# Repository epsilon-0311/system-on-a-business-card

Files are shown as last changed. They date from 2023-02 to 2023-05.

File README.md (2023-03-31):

# system-on-a-business-card (SoBC)

The System on a Business Card is a miniature system in the size of a business card.
It is controlled by a ESP32-C3 microncontroller which shall run Zephyr RTOS in the future.
Since this goal is to also use the PCB is a business card, the predominant factor is the size which is 55x85 mm which seems to be the standard, at least for Europe.

A interactive Bill of Materials for the latest released board revision can be found [here](KiCAD/system-on-a-business-card/bom/ibom.html).
Alternatively, if you have the repositoy open on Github, please use this [link](https://htmlpreview.github.io/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). 

For further details on how to customize the desing to add your contact details please have a look at [Customization of the PCB](KiCAD/doc/README.md#Customization-of-the-PCB).

## Hardware Design

The system uses the on-board USB Type C recepticle for power delivery and a ESP32-C3 as its host.
As the microcontroller also supports Bluetooth and Wifi the design includes a PCB antenna as well.
One of the most prominent elements of the board is 0.77 inch OLED screen which is used to display various graphics.
Instead of using typical low profile buttons the board has resistive touch pads for the main controls.
More details on the harware design can be found [here](KiCAD/doc/README.md).

Design renderings of a revision 1.A PCB:
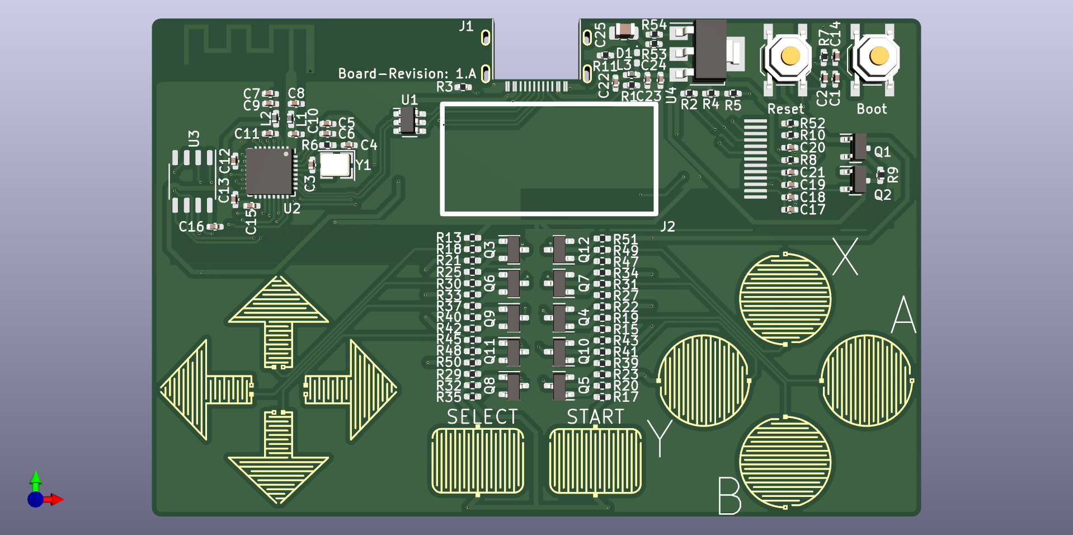
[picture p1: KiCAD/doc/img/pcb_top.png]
PCB_Top

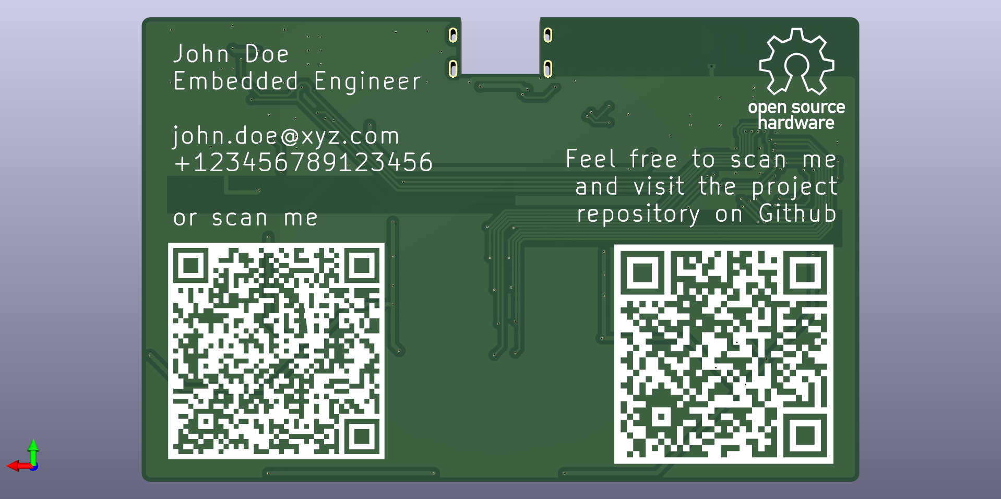
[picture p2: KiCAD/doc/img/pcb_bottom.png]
PCB_Bottom

Finished board revision 1.A PCB:
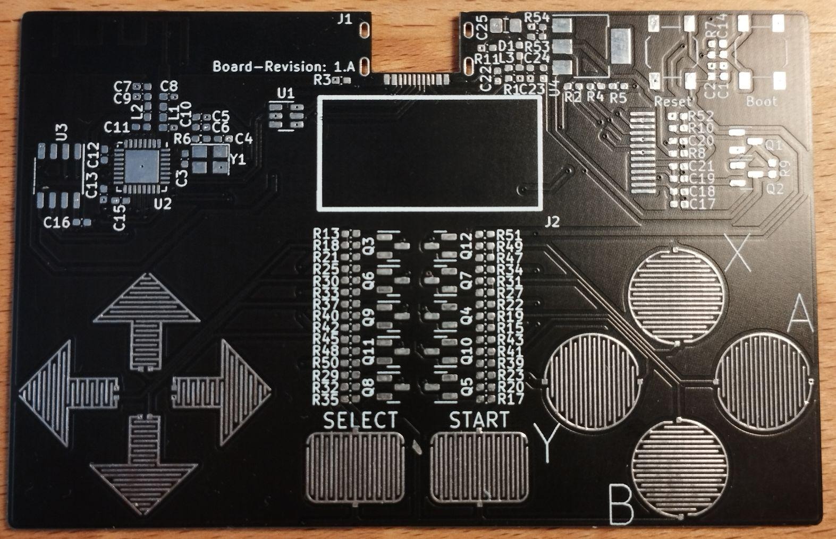
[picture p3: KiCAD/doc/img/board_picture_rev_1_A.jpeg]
board_picture_rev_1_A


Fully assembled revision 1.A PCB:
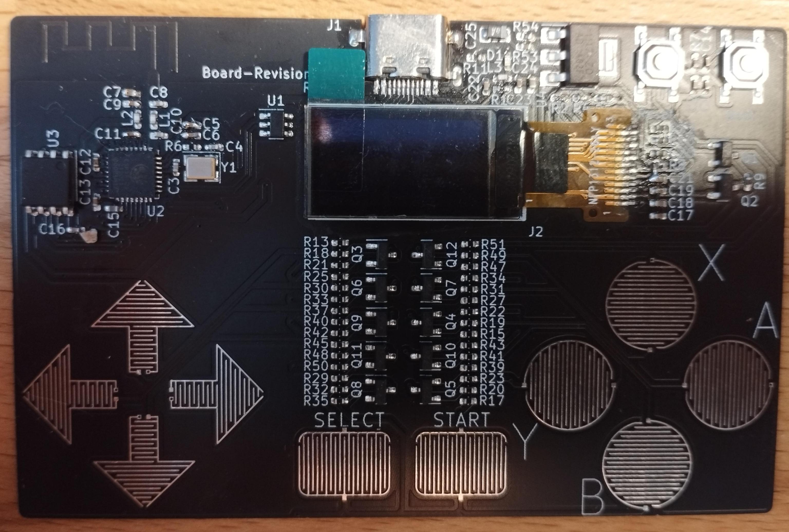
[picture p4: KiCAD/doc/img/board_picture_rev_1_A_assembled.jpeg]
assembled_board_picture_rev_1_A


## Zephyr
At the moment I'm working on getting Zephyr running.
A basic hardware configuration for the board is already available inside the Zephyr directory.
It builds and a minimal example is also available.
Unfortunately, I'm still waiting on my parts to finish the boards of my first batch.

As soon as I have a functioning board configuration, the goal is to submit the board to Zephry such that is officially supported.
Further, Zephyr currently does not support the used OLED dispaly controller (SSD1312).
Therefore, an additional goal is to submit a driver to the Zephyr project.

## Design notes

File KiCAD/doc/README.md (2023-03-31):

# Hardware Design

The system uses the on-board USB Type C recepticle for power delivery and converts the 5V to 3.3V using an LDO.
Since the ESP32-C3 has a USB interface and provides a serial interface as well as a JTAG no additional UART connector is on the board.
As the microcontroller also supports the connection of an antenne, there is also a PCB inverted F antenna on the top left of the board.
One of the most prominent elements of the board is 0.77 inch OLED screen which is connected via I2C to the host and is powered via the USB's 5V.
Instead of using typical low profile buttons, like on the top for BOOT and RESET, the board has resistive touch pads. 
As a small added benefit this design decision also reduces costs.

Since this PCB was designed to be also used as a business card, we opted for a thickness of 0.8mm. 
Main reason for the selected thickness, is that JLCPCB does not charge extra for PCB's between 0.8 and 1.6 mm.
This has to be taken with a grain of salt, other may charge extra for this.
The design for the antenna would be simpler to match the impedance, if a 4-Layer would be used. 
Unfortunately, with the thinner PCB significant extra costs would be added when using more layers.

## Board Revision History

A board revisions looks as follows ``MAJOR.MINOR.PATCH``.
``MAJOR`` revisions indicate some fundamental changes in the design, e.g, a new host. 
``MINOR`` revisions indicate changes in the hardware design, which requires a change in e.g. the Zephyr device tree.
Different ``PATCH`` versions indicate some minor changes in the design, which does not affect the software side.

| Revision | Local Link | Github Link | Release Package | Comments |
|---|---|---|---|---|
| 1.0.0/1.A  | [BOM](../system-on-a-business-card/bom/ibom_rev_1_0_0.html) | [BOM](https://htmlpreview.github.io/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)| [Package](https://github.com/epsilon-0311/system-on-a-business-card/releases/tag/board_rev_1_0_0) | Initial Version |
| 1.0.1 | [BOM](../system-on-a-business-card/bom/ibom_rev_1_0_1.html) | [BOM](https://htmlpreview.github.io/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)| [Package](https://github.com/epsilon-0311/system-on-a-business-card/releases/tag/board_rev_1_0_1) | <ul><li>Fixed unconnected OLED Logic Supply Voltage</li><li>Updated Resistor to dimm LED D1</li><li>Fixed Flash  IC Footprint</li></ul> |

The first batch was produced using the revision 1.A.
In order to provide a revision compatible with Zephyr, it was changed to ``1.0.0``.

## Antenna Impedance Trace Width Matching

As this design utilises a PCB Antenna, impedance matched traces are required.
The calculations assummed a surface micrstrip design.
From the manufacturer JLCPCB we know a copper thickness of 1 oz/35µm(see [Finished Outer Layer Copper](https://jlcpcb.com/capabilities/pcb-capabilities)) and a dilectric contant of 4.5 (see [Dielectric constant](https://jlcpcb.com/capabilities/pcb-capabilities)).
Using this [calculator](https://www.pcbway.com/pcb_prototype/impedance_calculator.html) we calculated a required track width of 1.45 mm to achieve a impedance of 50 Ohm.
Due to space limiations we opted for a trace width of 1.2 mm.

# Customization of the PCB
As this is a business card, it shall display your contact information.
Therefore, the bottom silkscreen layer provides a text field for this.
In addition, below the text field I added a QR-Code which was generated using [this online generator](https://goqr.me/#t=vcard). 

To modify this open the PCB design view of KiCAD and best hide all layers except Edge.Cuts and B.Silkscreen.
On the right side you find the text box for your contact information and below there is some space to place the QR-Code.
The QR-Code needs to be available as svg graphic and can be imported via File->Import->Graphics.
If you use the same generator, you can import the svg with a scaling factor of 0.375.

# Sourcing Guide 

You can find a sourcing guide using [JLCPCB](https://jlcpcb.com/) and [LCSC](https://www.lcsc.com/) as PCB manufacturer and parts suppliere here: [Link](https://docs.google.com/spreadsheets/d/16gFrFvvIfR94LbLsq9TxAxXNphaDNR22jH06x7NUitE/edit?usp=sharing). 
With the components selected in this Google Spreads, a single PCB with parts will cost around 4€, if at least 10 are manufactured.
Due to varying costs on the shipment destination, shipment costs were not included in the calculation.

The original goal was to be at around 3€ per board.
The main cost factors are the used microcontroller (ESP32-C3) and the 0.77 inch OLED display.
If you are aware of components that can reduce the price, feel free to discuss it in the discussion section on GitHub. 

# Possible Future updates to the Design

## ESP32-C6
Esprressif has announced the ESP32-C6 with a high and a lowe power core and more wireless connectivity standards.
At the moment the chip is not available on my default parts provider (LCSC), but it would be nice to check it out due to its more powerfull CPU.
Further investigation is strongly dependent on the price.

## USB Ciruitry
Currently the design simply pulls power through the USB plug, but this violates the USB specification. 
For future revisions it would be awesome to add a USB power negotion circuit to board to add comformoty. 
If you're familiar with the design of such circuits feel free to add some comments.

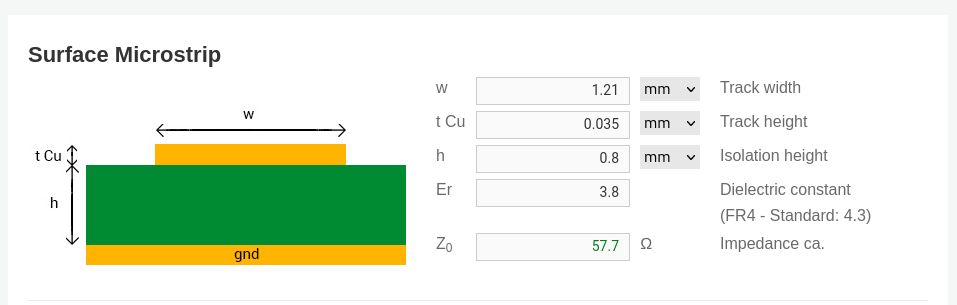
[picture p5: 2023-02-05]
KiCAD/doc/img/impedance_calculation.png

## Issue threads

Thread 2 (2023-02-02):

Zephyr Bring-Up

epsilon-0311, 2023-02-02:
To get Zephyr running on a new board the following steps need to be performed.

- [x] devicetree file : Hardware definition file
- [x] KConfig files : Softare configuration files
- - [x] Kconfig.board
- - [x] Kconfig.defconfig
- - [x]  sobc_defconfig

Optional Files

- [x] board.cmake : Build and flash configuration
- [ ] ~~ doc/index.rst and doc/sobc.png : Documentation for submission to Zephyr ~~
- [ ] ~~ sobc.yaml: a YAML file with miscellaneous metadata used by the Test Runner (Twister) ~~

Steps:
- [x]  Get Zephyr Running
- [ ]  ~~ Add Documentation ~~
- [ ]  ~~  Contibute to [Zephyr](https://docs.zephyrproject.org/latest/hardware/porting/board_porting.html#contributing-your-board)~~

epsilon-0311, 2023-02-03:
Hardware and Software configuration files added and compile. Final testing requires hardware which is still in transit

epsilon-0311, 2023-03-25:
The board does not use a dedicated UART interface. Instead, it uses USB-CDC, which needs to be configured for Zephyr

epsilon-0311, 2023-09-02:
Zephyr now works, closing issue

Closed 2023-09-02.

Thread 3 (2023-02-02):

USB Power Delivery

epsilon-0311, 2023-02-02:
Currently, the board simply takes power from the USB-Receptacle violating the Specification.
In the future the board shall use circuitry such this is compliant.

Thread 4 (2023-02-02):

OLED driver

epsilon-0311, 2023-02-02:
The used [OLED display](https://www.lcsc.com/product-detail/_Shenzhen-Allvision-Tech-_C5123562.html) uses the [SSD1312](https://www.buydisplay.com/download/ic/SSD1312_Datasheet.pdf).
This controller is not officially supported by Zephry.

- [x] Check SSD1306 [datasheet](https://cdn-shop.adafruit.com/datasheets/SSD1306.pdf)  and [driver](https://github.com/zephyrproject-rtos/zephyr/tree/main/boards/shields/ssd1306)
- [x] Create SSD1312 shield device tree overlay
- [x] Implement SSD1312 driver
- [x] Add SSD1312 to board device tree
- [ ] Contribute driver to Zephyr

epsilon-0311, 2023-04-08:
Checkout the files from SSD1306:

- [ssd1306_128x64.overlay](https://github.com/zephyrproject-rtos/zephyr/blob/main/boards/shields/ssd1306/ssd1306_128x64.overlay)
- [ssd1306.c](https://github.com/zephyrproject-rtos/zephyr/blob/main/drivers/display/ssd1306.c)
- [KConfig](https://github.com/zephyrproject-rtos/zephyr/blob/main/drivers/display/Kconfig.ssd1306)

epsilon-0311, 2023-04-08:
Checkout the files from SSD1306:

- [ssd1306_128x64.overlay](https://github.com/zephyrproject-rtos/zephyr/blob/main/boards/shields/ssd1306/ssd1306_128x64.overlay)
- [ssd1306.c](https://github.com/zephyrproject-rtos/zephyr/blob/main/drivers/display/ssd1306.c)
- [KConfig](https://github.com/zephyrproject-rtos/zephyr/blob/main/drivers/display/Kconfig.ssd1306)

epsilon-0311, 2023-06-11:
Contribution to Zephyr is skipped for now.

Closed 2023-06-11.

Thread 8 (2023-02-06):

SMT Stencil Mount

epsilon-0311, 2023-02-06:
Would be nice to design a SMT stencil holder for easy application of the solder paste. It should be 3D-printable.

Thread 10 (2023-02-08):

Board Revision 1.0.1

epsilon-0311, 2023-02-08:
In this issue planned improvements for the board revision 1.0.1 are stored:

- [ ]  add rounded corners to the USB Plug cut out

epsilon-0311, 2023-03-10:
the voltage divider should work without the transistor switching the MCU, check if this is possible  as it would significantly reduce the component count

epsilon-0311, 2023-04-06:
Test using the voltage divider without the transistor, still works. This should be implemented to reduce component count.

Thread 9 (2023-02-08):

Scripting Support

epsilon-0311, 2023-02-08:
KiCAD has a python API which allows scripting amongst other things an automated export of gerber files.
It would be nice to provide some tooling which eases swapping QR-codes and contact details

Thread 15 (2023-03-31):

Connection to LED inside PI Filter

epsilon-0311, 2023-03-31:
The connection to the LED D1 is inside the PI filter.  The wire should be moved after the filter.

Closed 2023-03-31.

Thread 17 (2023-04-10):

ZD1117ILTRAD resistor values

epsilon-0311, 2023-04-10:
I rechecked the design guidelines for the ZD1117ILTRAD, the current design works but the resistors should be adapted to meet the guidelines

epsilon-0311, 2023-04-10:
Replace R53 with a 121 Ohm and R54 with 75 Ohm Resistor

Closed 2023-04-10.

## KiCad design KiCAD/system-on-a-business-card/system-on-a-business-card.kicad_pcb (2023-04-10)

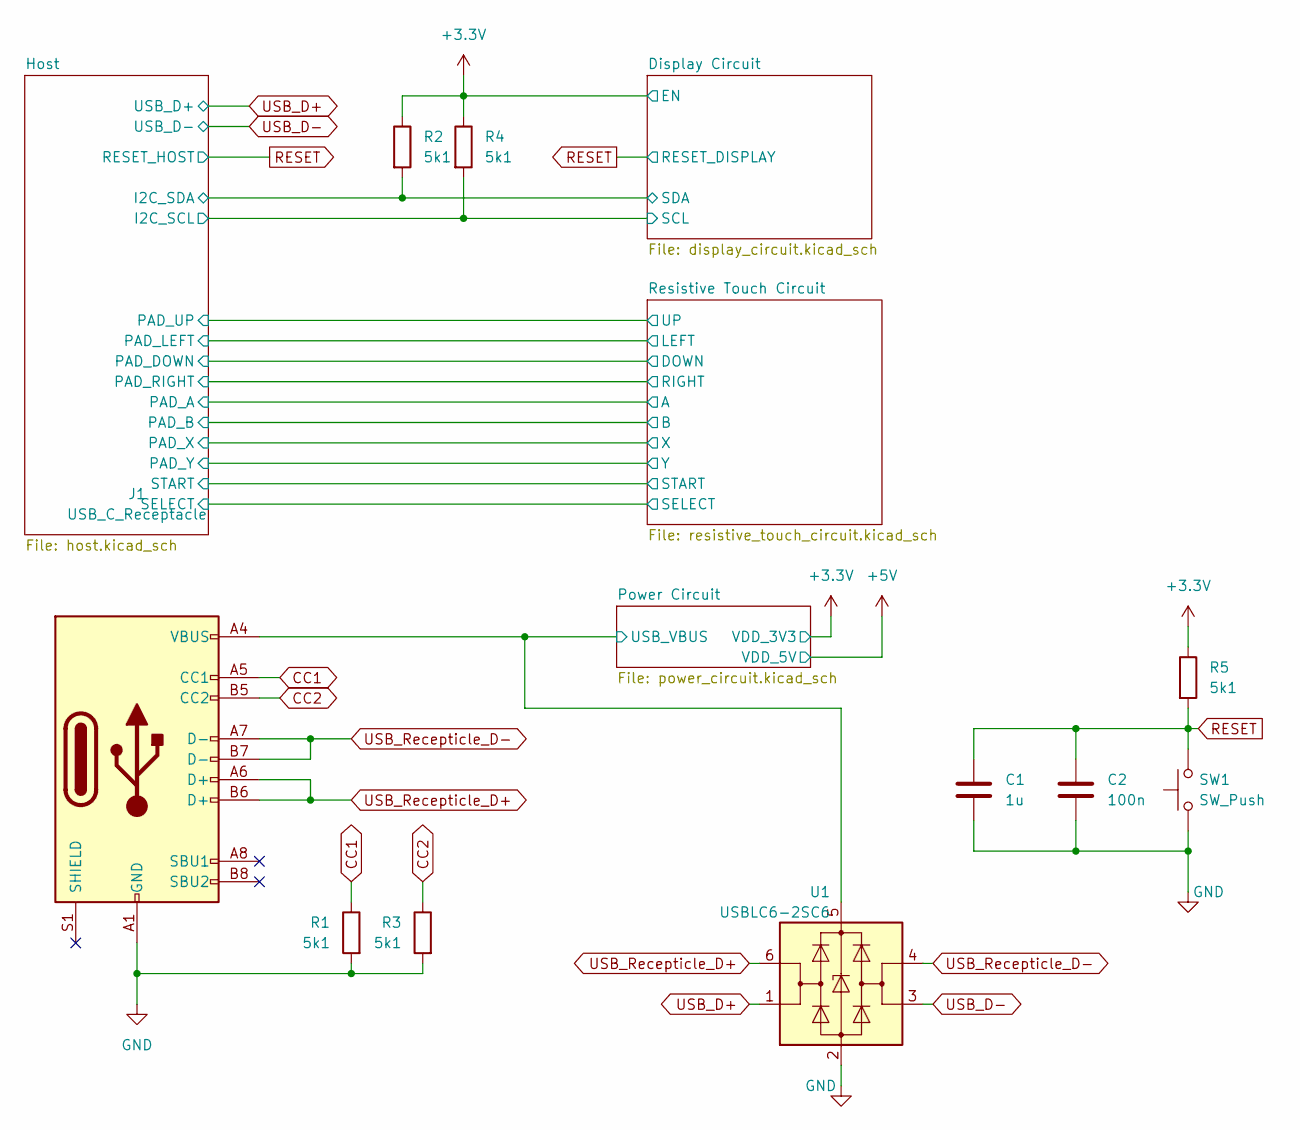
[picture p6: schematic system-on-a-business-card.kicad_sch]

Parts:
C1: 1u; C_0402_1005Metric_Pad0.74x0.62mm_HandSolder
C2: 100n; C_0402_1005Metric_Pad0.74x0.62mm_HandSolder
J1: USB_C_Receptacle; USB_C_Receptacle_SHOU_HAN_TYPE_C_16P_CB1.6_073
R1, R2, R3, R4, R5: 5k1; R_0402_1005Metric_Pad0.72x0.64mm_HandSolder
SW1: SW_Push; SW_SPST_TL3342
U1: USBLC6-2SC6; SOT-23-6

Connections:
+3.3V: R2.1, R4.1, R5.1; also elsewhere on the board
/Display Circuit/SCL: R4.2; also elsewhere on the board
/Display Circuit/SDA: R2.2; also elsewhere on the board
/Power Circuit/USB_VBUS: J1.A4 (VBUS), J1.A9 (VBUS), J1.B4 (VBUS), J1.B9 (VBUS), U1.5 (VBUS); also elsewhere on the board
CC1: J1.A5 (CC1), R1.1
CC2: J1.B5 (CC2), R3.1
GND: C1.2, C2.2, J1.A1 (GND), J1.A12 (GND), J1.B1 (GND), J1.B12 (GND), R1.2, R3.2, SW1.1, U1.2 (GND); also elsewhere on the board
RESET: C1.1, C2.1, R5.2, SW1.2; also elsewhere on the board
USB_D+: U1.1 (I/O1); also elsewhere on the board
USB_D-: U1.3 (I/O2); also elsewhere on the board
USB_Recepticle_D+: J1.A6 (D+), J1.B6 (D+), U1.6 (I/O1)
USB_Recepticle_D-: J1.A7 (D-), J1.B7 (D-), U1.4 (I/O2)

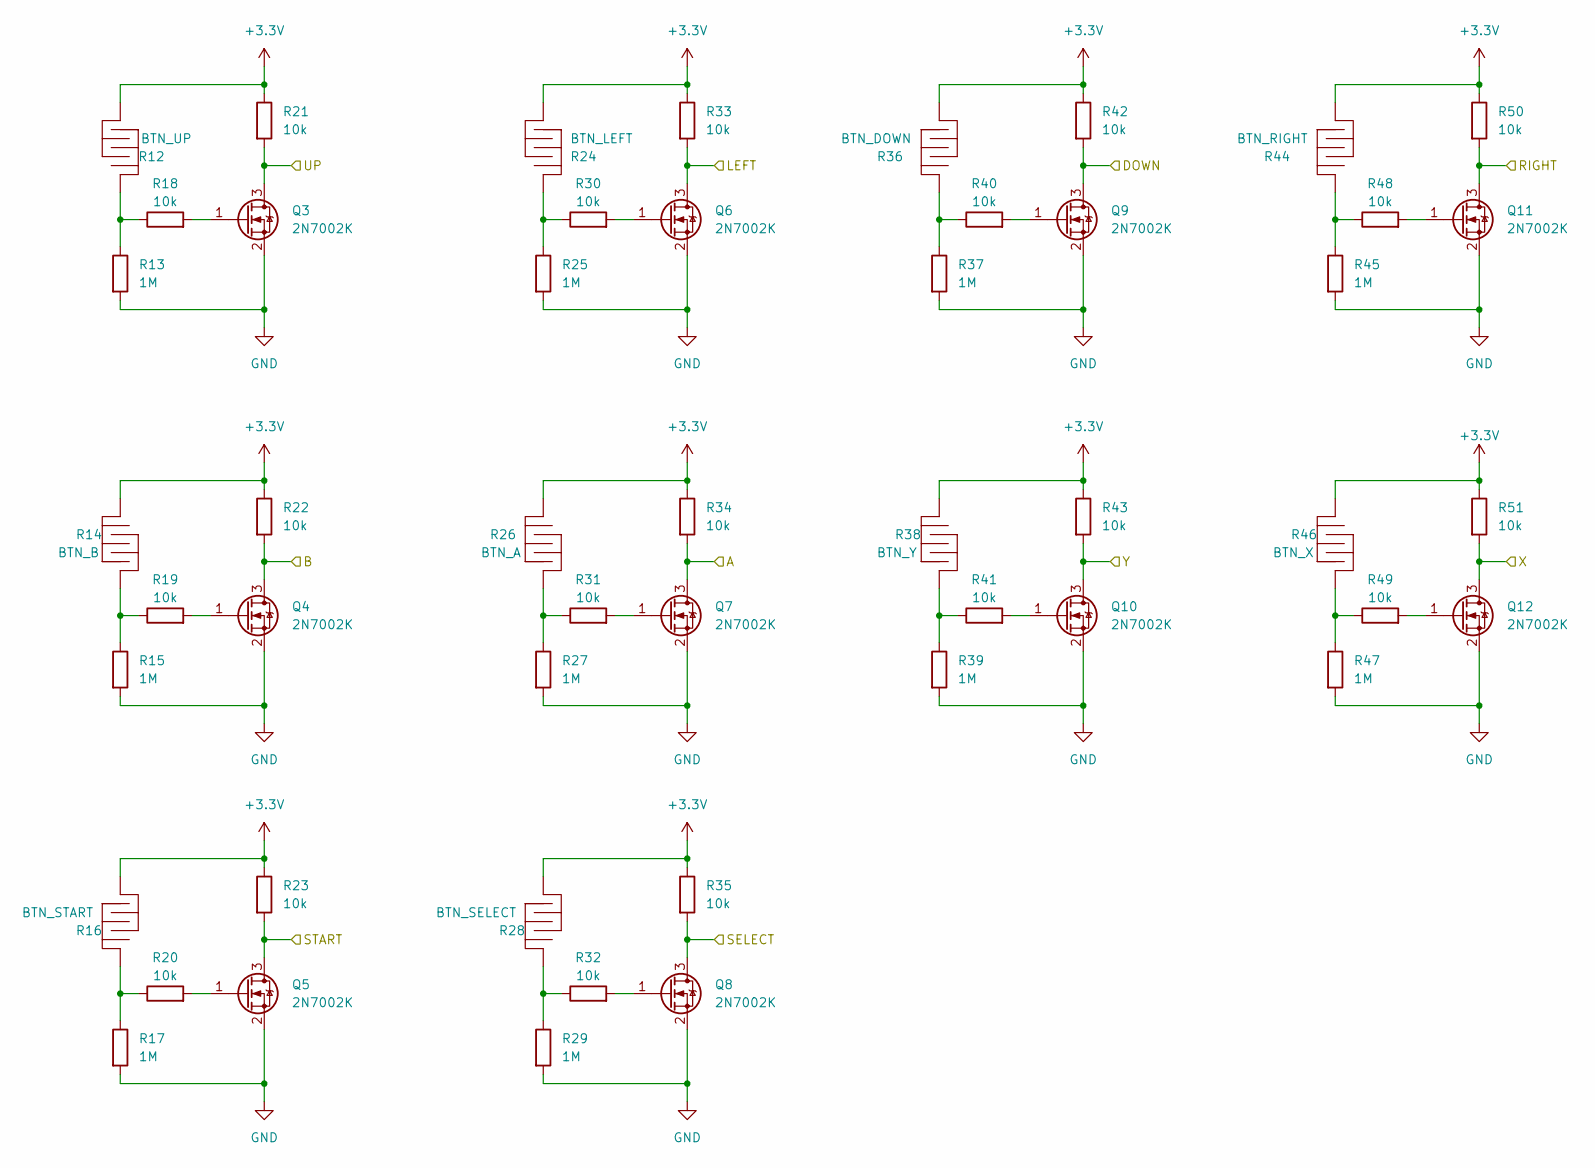
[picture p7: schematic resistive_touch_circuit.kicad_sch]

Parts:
Q3, Q4, Q5, Q6, Q7, Q8, Q9, Q10, Q11, Q12: 2N7002K; SOT-23
R12: BTN_UP; Resistive_Pad_Arrow_10mm
R13, R15, R17, R25, R27, R29, R37, R39, R45, R47: 1M; R_0402_1005Metric_Pad0.72x0.64mm_HandSolder
R14: BTN_B; Resistive_Pad_round_10_mm
R16: BTN_START; Resistive_Pad_rectangular_rounded_7x10mm
R18, R19, R20, R21, R22, R23, R30, R31, R32, R33, R34, R35, R40, R41, R42, R43, R48, R49, R50, R51: 10k; R_0402_1005Metric_Pad0.72x0.64mm_HandSolder
R24: BTN_LEFT; Resistive_Pad_Arrow_10mm
R26: BTN_A; Resistive_Pad_round_10_mm
R28: BTN_SELECT; Resistive_Pad_rectangular_rounded_7x10mm
R36: BTN_DOWN; Resistive_Pad_Arrow_10mm
R38: BTN_Y; Resistive_Pad_round_10_mm
R44: BTN_RIGHT; Resistive_Pad_Arrow_10mm
R46: BTN_X; Resistive_Pad_round_10_mm

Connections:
+3.3V: R12.2, R14.1, R16.2, R21.1, R22.1, R23.1, R24.2, R26.1, R28.2, R33.1, R34.1, R35.1, R36.2, R38.1, R42.1, R43.1, R44.2, R46.1, R50.1, R51.1; also elsewhere on the board
/Host/PAD_A: Q7.3 (D), R34.2; also elsewhere on the board
/Host/PAD_B: Q4.3 (D), R22.2; also elsewhere on the board
/Host/PAD_DOWN: Q9.3 (D), R42.2; also elsewhere on the board
/Host/PAD_LEFT: Q6.3 (D), R33.2; also elsewhere on the board
/Host/PAD_RIGHT: Q11.3 (D), R50.2; also elsewhere on the board
/Host/PAD_UP: Q3.3 (D), R21.2; also elsewhere on the board
/Host/PAD_X: Q12.3 (D), R51.2; also elsewhere on the board
/Host/PAD_Y: Q10.3 (D), R43.2; also elsewhere on the board
/Host/SELECT: Q8.3 (D), R35.2; also elsewhere on the board
/Host/START: Q5.3 (D), R23.2; also elsewhere on the board
GND: Q3.2 (S), Q4.2 (S), Q5.2 (S), Q6.2 (S), Q7.2 (S), Q8.2 (S), Q9.2 (S), Q10.2 (S), Q11.2 (S), Q12.2 (S), R13.2, R15.2, R17.2, R25.2, R27.2, R29.2, R37.2, R39.2, R45.2, R47.2; also elsewhere on the board
unnamed: Q3.1 (G), R18.2
unnamed: Q4.1 (G), R19.2
unnamed: Q5.1 (G), R20.2
unnamed: Q6.1 (G), R30.2
unnamed: Q7.1 (G), R31.2
unnamed: Q8.1 (G), R32.2
unnamed: Q9.1 (G), R40.2
unnamed: Q10.1 (G), R41.2
unnamed: Q11.1 (G), R48.2
unnamed: Q12.1 (G), R49.2
unnamed: R12.1, R13.1, R18.1
unnamed: R14.2, R15.1, R19.1
unnamed: R16.1, R17.1, R20.1
unnamed: R24.1, R25.1, R30.1
unnamed: R26.2, R27.1, R31.1
unnamed: R28.1, R29.1, R32.1
unnamed: R36.1, R37.1, R40.1
unnamed: R38.2, R39.1, R41.1
unnamed: R44.1, R45.1, R48.1
unnamed: R46.2, R47.1, R49.1

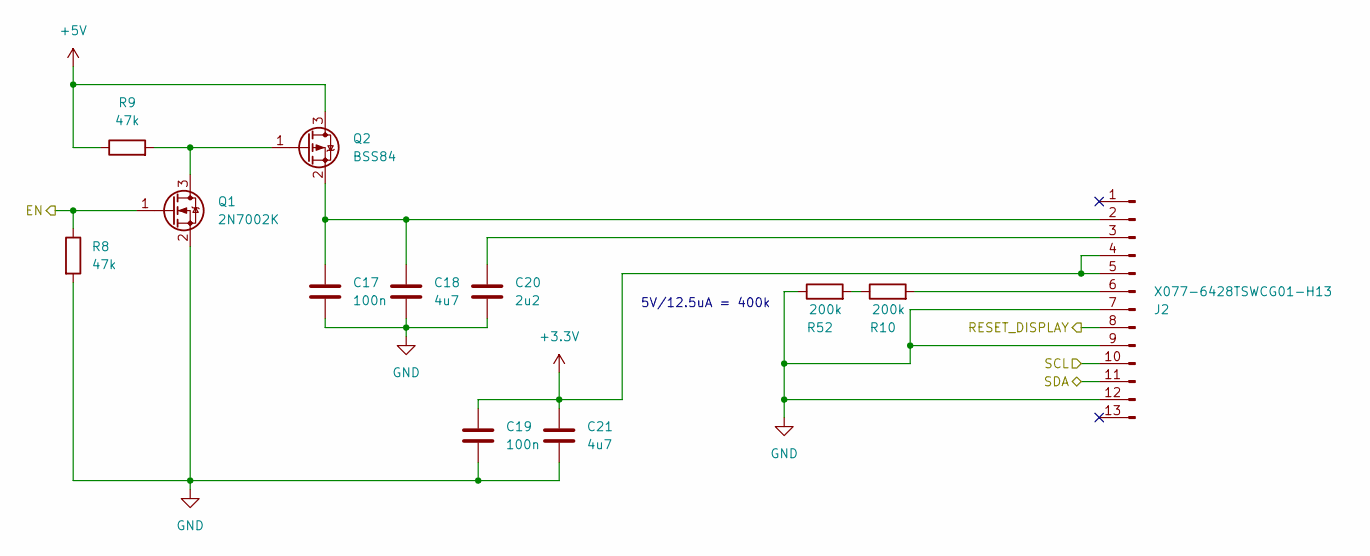
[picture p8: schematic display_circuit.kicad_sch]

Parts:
C17, C19: 100n; C_0402_1005Metric_Pad0.74x0.62mm_HandSolder
C18, C21: 4u7; C_0402_1005Metric_Pad0.74x0.62mm_HandSolder
C20: 2u2; C_0402_1005Metric_Pad0.74x0.62mm_HandSolder
J2: X077-6428TSWCG01-H13
Q1: 2N7002K; SOT-23
Q2: BSS84; SOT-23
R8, R9: 47k; R_0402_1005Metric_Pad0.72x0.64mm_HandSolder
R10, R52: 200k; R_0402_1005Metric_Pad0.72x0.64mm_HandSolder

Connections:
+3.3V: C19.1, C21.1, J2.4, J2.5, Q1.1 (G), R8.1; also elsewhere on the board
+5V: Q2.3 (D), R9.1; also elsewhere on the board
/Display Circuit/SCL: J2.10; also elsewhere on the board
/Display Circuit/SDA: J2.11; also elsewhere on the board
GND: C17.2, C18.2, C19.2, C20.2, C21.2, J2.7, J2.9, J2.12, Q1.2 (S), R8.2, R52.1; also elsewhere on the board
unnamed: C17.1, C18.1, J2.2, Q2.2 (S)
unnamed: C20.1, J2.3
unnamed: J2.6, R10.2
unnamed: Q1.3 (D), Q2.1 (G), R9.2
unnamed: R10.1, R52.2
RESET: J2.8; also elsewhere on the board

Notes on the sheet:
5V/12.5uA = 400k

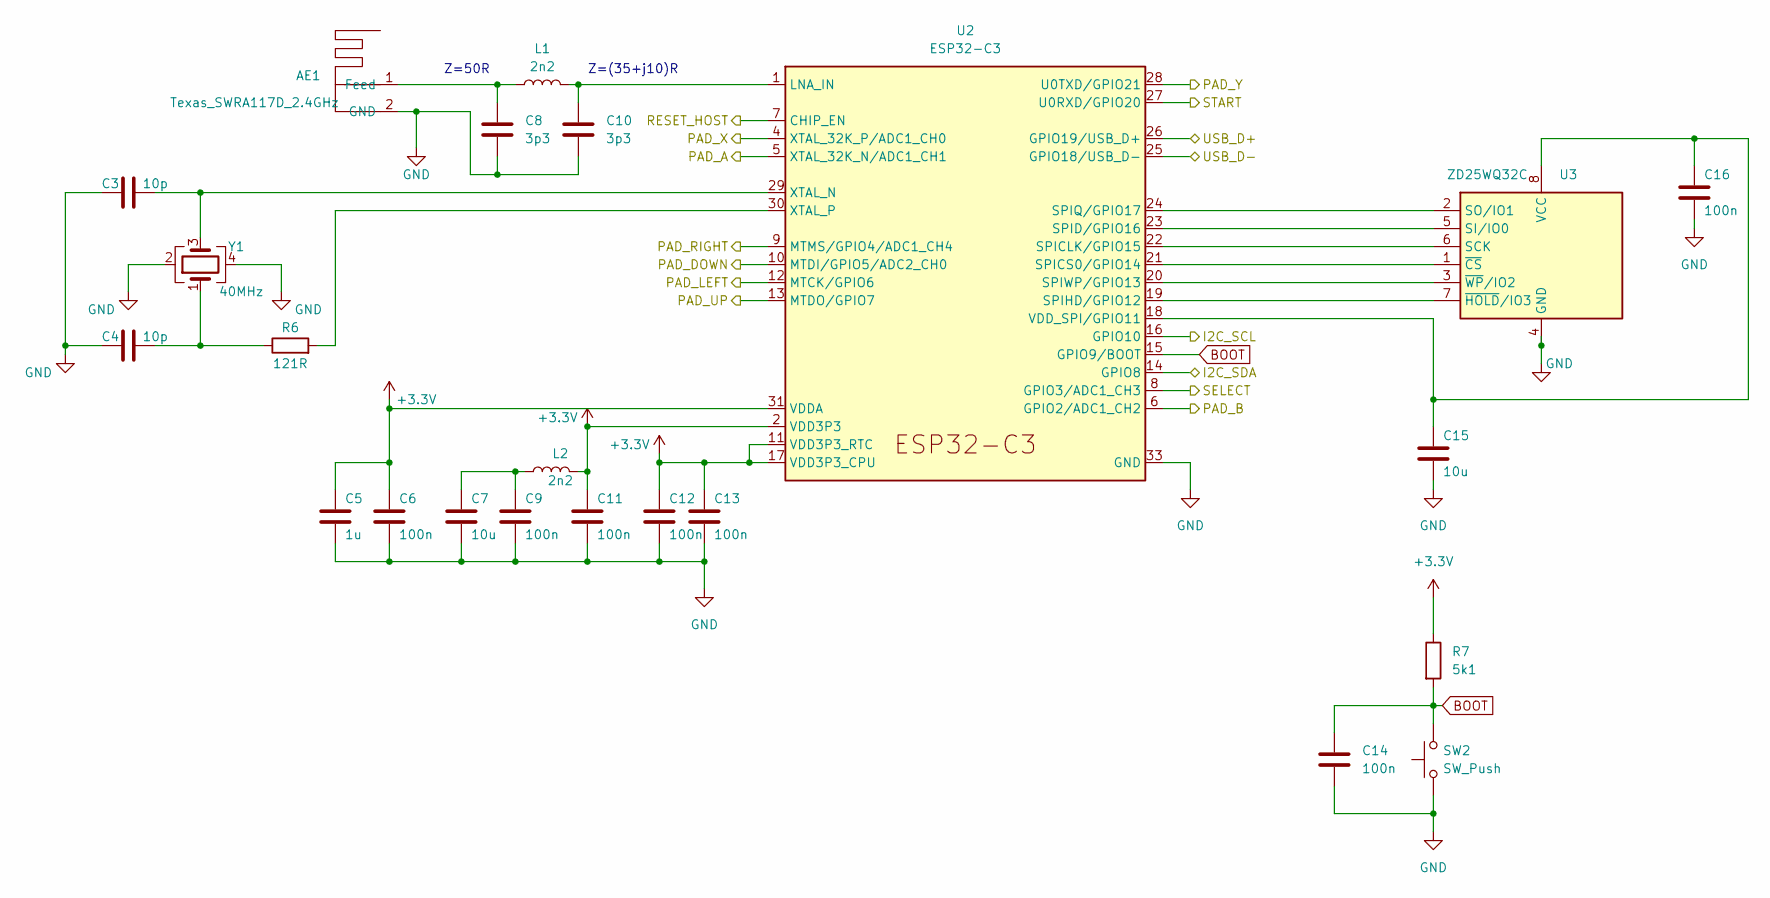
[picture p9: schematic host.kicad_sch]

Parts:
AE1: Texas_SWRA117D_2.4GHz; Texas_SWRA117D_2.4GHz_Left
C3, C4: 10p; C_0402_1005Metric_Pad0.74x0.62mm_HandSolder
C5: 1u; C_0402_1005Metric_Pad0.74x0.62mm_HandSolder
C6, C9, C11, C12, C13, C14, C16: 100n; C_0402_1005Metric_Pad0.74x0.62mm_HandSolder
C7, C15: 10u; C_0402_1005Metric_Pad0.74x0.62mm_HandSolder
C8, C10: 3p3; C_0402_1005Metric_Pad0.74x0.62mm_HandSolder
L1, L2: 2n2; L_0402_1005Metric_Pad0.77x0.64mm_HandSolder
R6: 121R; R_0402_1005Metric_Pad0.72x0.64mm_HandSolder
R7: 5k1; R_0402_1005Metric_Pad0.72x0.64mm_HandSolder
SW2: SW_Push; SW_SPST_TL3342
U2: ESP32-C3; QFN-32-1EP_5x5mm_P0.5mm_EP3.45x3.45mm
U3: ZD25WQ32C; SOP-8_5.28x5.23mm_P1.27mm
Y1: 40MHz; Crystal_SMD_3225-4Pin_3.2x2.5mm

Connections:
+3.3V: C5.1, C6.1, C11.1, C12.1, C13.1, L2.2, R7.1, U2.2 (VDD3P3), U2.3 (VDD3P3), U2.11 (VDD3P3_RTC), U2.17 (VDD3P3_CPU), U2.31 (VDDA), U2.32 (VDDA); also elsewhere on the board
/Display Circuit/SCL: U2.16 (GPIO10); also elsewhere on the board
/Display Circuit/SDA: U2.14 (GPIO8); also elsewhere on the board
/Host/PAD_A: U2.5 (XTAL_32K_N/ADC1_CH1); also elsewhere on the board
/Host/PAD_B: U2.6 (GPIO2/ADC1_CH2); also elsewhere on the board
/Host/PAD_DOWN: U2.10 (MTDI/GPIO5/ADC2_CH0); also elsewhere on the board
/Host/PAD_LEFT: U2.12 (MTCK/GPIO6); also elsewhere on the board
/Host/PAD_RIGHT: U2.9 (MTMS/GPIO4/ADC1_CH4); also elsewhere on the board
/Host/PAD_UP: U2.13 (MTDO/GPIO7); also elsewhere on the board
/Host/PAD_X: U2.4 (XTAL_32K_P/ADC1_CH0); also elsewhere on the board
/Host/PAD_Y: U2.28 (U0TXD/GPIO21); also elsewhere on the board
/Host/SELECT: U2.8 (GPIO3/ADC1_CH3); also elsewhere on the board
/Host/START: U2.27 (U0RXD/GPIO20); also elsewhere on the board
BOOT: C14.1, R7.2, SW2.2, U2.15 (GPIO9/BOOT)
GND: AE1.2 (GND), C3.1, C4.1, C5.2, C6.2, C7.2, C8.2, C9.2, C10.2, C11.2, C12.2, C13.2, C14.2, C15.2, C16.2, SW2.1, U2.33 (GND), U3.4 (GND), Y1.2, Y1.4; also elsewhere on the board
unnamed: AE1.1 (Feed), C8.1, L1.1
unnamed: C4.2, R6.1, Y1.1
unnamed: C7.1, C9.1, L2.1
unnamed: C10.1, L1.2, U2.1 (LNA_IN)
unnamed: U2.22 (SPICLK/GPIO15), U3.6 (SCK)
unnamed: U2.21 (SPICS0/GPIO14), U3.1 (~CS)
unnamed: U2.23 (SPID/GPIO16), U3.5 (SI/IO0)
unnamed: U2.19 (SPIHD/GPIO12), U3.7 (~HOLD/IO3)
unnamed: U2.24 (SPIQ/GPIO17), U3.2 (SO/IO1)
unnamed: U2.20 (SPIWP/GPIO13), U3.3 (~WP/IO2)
unnamed: C15.1, C16.1, U2.18 (VDD_SPI/GPIO11), U3.8 (VCC)
unnamed: C3.2, U2.29 (XTAL_N), Y1.3
unnamed: R6.2, U2.30 (XTAL_P)
RESET: U2.7 (CHIP_EN); also elsewhere on the board
USB_D+: U2.26 (GPIO19/USB_D+); also elsewhere on the board
USB_D-: U2.25 (GPIO18/USB_D-); also elsewhere on the board

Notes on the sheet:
Z=(35+j10)R
Z=50R

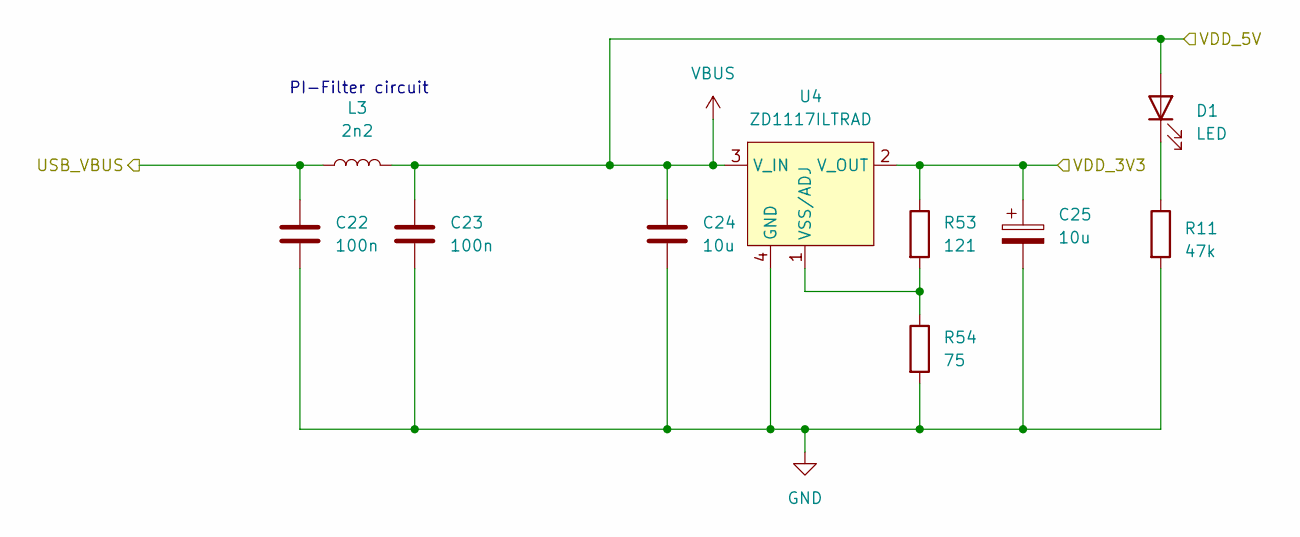
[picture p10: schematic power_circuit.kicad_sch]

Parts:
C22, C23: 100n; C_0402_1005Metric_Pad0.74x0.62mm_HandSolder
C24: 10u; C_0402_1005Metric_Pad0.74x0.62mm_HandSolder
C25: 10u; C_0805_2012Metric_Pad1.18x1.45mm_HandSolder
D1: LED; D_0402_1005Metric_Pad0.77x0.64mm_HandSolder
L3: 2n2; L_0402_1005Metric_Pad0.77x0.64mm_HandSolder
R11: 47k; R_0402_1005Metric_Pad0.72x0.64mm_HandSolder
R53: 121; R_0402_1005Metric_Pad0.72x0.64mm_HandSolder
R54: 75; R_0402_1005Metric_Pad0.72x0.64mm_HandSolder
U4: ZD1117ILTRAD; SOT-223

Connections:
+3.3V: C25.1, R53.1, U4.2 (V_OUT); also elsewhere on the board
+5V: C23.1, C24.1, D1.2 (A), L3.2, U4.3 (V_IN); also elsewhere on the board
/Power Circuit/USB_VBUS: C22.1, L3.1; also elsewhere on the board
GND: C22.2, C23.2, C24.2, C25.2, R11.2, R54.2, U4.4 (GND); also elsewhere on the board
unnamed: D1.1 (K), R11.1
unnamed: R53.2, R54.1, U4.1 (VSS/ADJ)

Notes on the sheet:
PI-Filter circuit

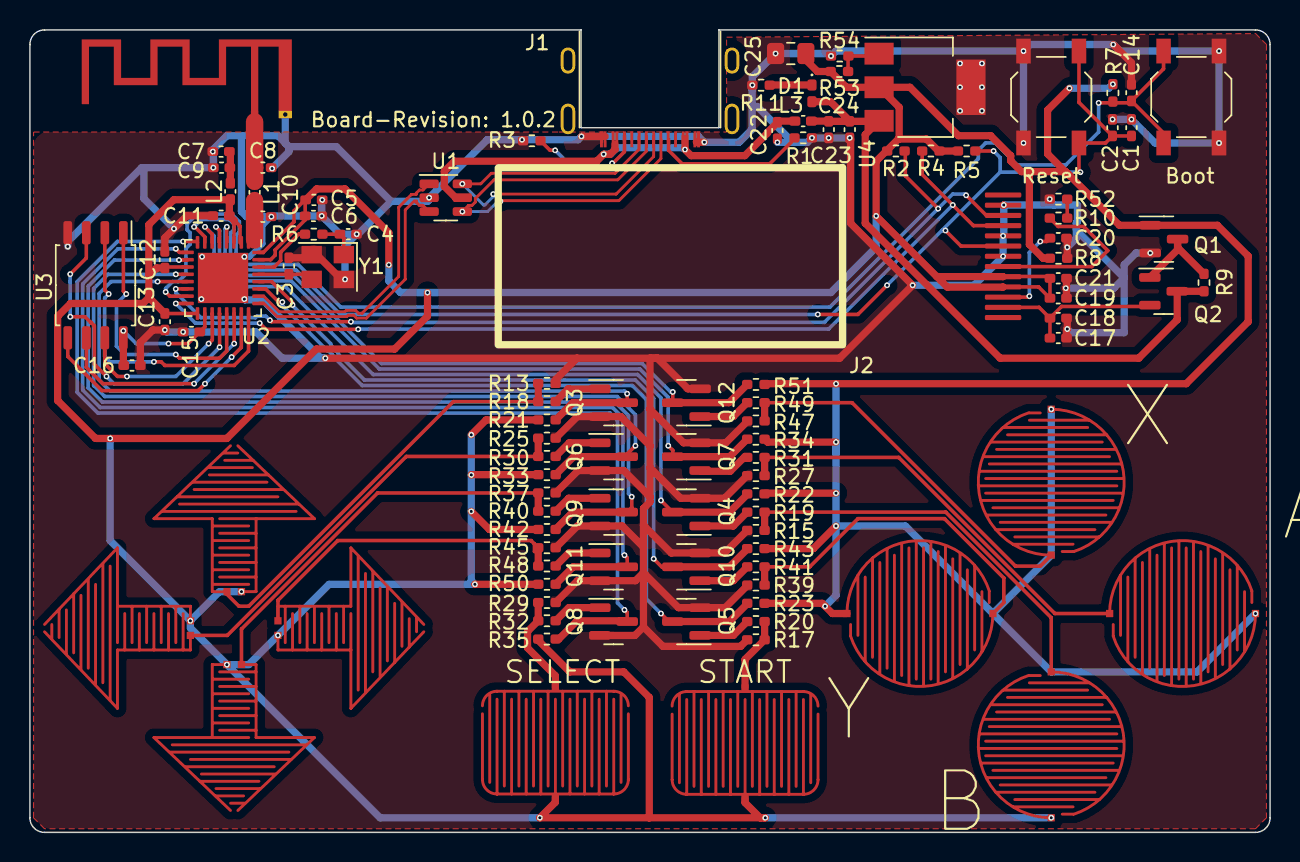
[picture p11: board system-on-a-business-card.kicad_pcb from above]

Board: 2 copper layers, 85.0 x 55.0 mm, 105 parts (0 on the bottom side), 64 nets.

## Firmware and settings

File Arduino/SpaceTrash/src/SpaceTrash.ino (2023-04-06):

/*

  SpaceTrash.ino

  Universal 8bit Graphics Library (https://github.com/olikraus/u8g2/)

  Copyright (c) 2016, olikraus@gmail.com
  All rights reserved.

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
  THIS SOFTWARE IS PROVIDED BY THE COPYRIGHT HOLDERS AND 
  CONTRIBUTORS "AS IS" AND ANY EXPRESS OR IMPLIED WARRANTIES, 
  INCLUDING, BUT NOT LIMITED TO, THE IMPLIED WARRANTIES OF 
  MERCHANTABILITY AND FITNESS FOR A PARTICULAR PURPOSE ARE 
  DISCLAIMED. IN NO EVENT SHALL THE COPYRIGHT HOLDER OR 
  CONTRIBUTORS BE LIABLE FOR ANY DIRECT, INDIRECT, INCIDENTAL, 
  SPECIAL, EXEMPLARY, OR CONSEQUENTIAL DAMAGES (INCLUDING, BUT 
  NOT LIMITED TO, PROCUREMENT OF SUBSTITUTE GOODS OR SERVICES; 
  LOSS OF USE, DATA, OR PROFITS; OR BUSINESS INTERRUPTION) HOWEVER 
  CAUSED AND ON ANY THEORY OF LIABILITY, WHETHER IN CONTRACT, 
  STRICT LIABILITY, OR TORT (INCLUDING NEGLIGENCE OR OTHERWISE) 
  ARISING IN ANY WAY OUT OF THE USE OF THIS SOFTWARE, EVEN IF 
  ADVISED OF THE POSSIBILITY OF SUCH DAMAGE.  

*/

#include <Arduino.h>
#include <EEPROM.h>
#include <U8g2lib.h>

#ifdef U8X8_HAVE_HW_SPI
#include <SPI.h>
#endif
#ifdef U8X8_HAVE_HW_I2C
#include <Wire.h>
#endif

// Please UNCOMMENT one of the contructor lines below
// U8g2 Contructor List (Picture Loop Page Buffer)
// The complete list is available here: https://github.com/olikraus/u8g2/wiki/u8g2setupcpp
// Please update the pin numbers according to your setup. Use U8X8_PIN_NONE if the reset pin is not connected
#define SDA 8
#define SCL 10
U8G2_SSD1312_128X64_NONAME_1_HW_I2C u8g2(U8G2_R0, U8X8_PIN_NONE, SCL, SDA);

// End of constructor list

#define PAD_RIGHT 4
#define PAD_DOWN 5
#define PAD_LEFT 6
#define PAD_UP 7

#define PAD_A 1
#define PAD_B 2
#define PAD_X 0
#define PAD_Y 21

#define PAD_SELECT 3
#define PAD_START 20


#define EEPROM_SIZE 64
#define EEPROM_MAGIC_ADDR 0
#define EEPROM_MAGIC_VALUE 0xAA
#define EEPROM_HIGHSCORE_ADDR 4


/* button setup for Arduboy Production */
uint8_t pin_up = PAD_UP;
uint8_t pin_down = PAD_DOWN;
uint8_t pin_left = PAD_LEFT;
uint8_t pin_right = PAD_RIGHT;


uint8_t pin_fire = PAD_A;
uint8_t pin_start = PAD_START;


#define ST_FP 4

/* object types */
struct _st_ot_struct
{
  /* 
    missle and hit: 
      bit 0: player missle and trash
      bit 1: trash, which might hit the player
  */
  
  uint8_t missle_mask;		/* this object is a missle: it might destroy something if the target is_hit_fn says so */ 
  uint8_t hit_mask;			/* if missle_mask & hit_mask is != 0  then the object can be destroyed */
  uint8_t points;
  uint8_t draw_fn;
  uint8_t move_fn;
      /* ST_MOVE_FN_NONE, ST_MOVE_FN_X_SLOW */
  uint8_t destroy_fn;		/* object can be destroyed by a missle (e.g. a missle from the space ship) */
      /* ST_DESTROY_FN_NONE, ST_DESTROY_FN_SPLIT */
  uint8_t is_hit_fn;		/* is hit procedure */
      /* ST_IS_HIT_FN_NONE, ST_IS_HIT_BBOX */
  uint8_t fire_fn;
    /* ST_FIRE_FN_NONE, ST_FIRE_FN_X_LEFT */
  
};
typedef struct _st_ot_struct st_ot;

/*
  objects, which are visible at the play area
*/
struct _st_obj_struct
{
  uint8_t ot; 			/* object type: zero means, object is not used */
  int8_t tmp;			/* generic value, used by ST_MOVE_IMPLODE */
  /* absolute position */
  /* LCD pixel position is x>>ST_FP and y>>ST_FP */
  int16_t x, y;
  int8_t x0,y0,x1,y1;	/* object outline in pixel, reference point is at 0,0 */
};
typedef struct _st_obj_struct st_obj;

#define ST_DRAW_NONE 0
#define ST_DRAW_BBOX 1
#define ST_DRAW_TRASH1 2
#define ST_DRAW_PLAYER1 3
#define ST_DRAW_TRASH2 4
#define ST_DRAW_PLAYER2 5
#define ST_DRAW_PLAYER3 6
#define ST_DRAW_GADGET 7
#define ST_DRAW_BACKSLASH 8
#define ST_DRAW_SLASH 9
#define ST_DRAW_BIG_TRASH 10

#define ST_MOVE_NONE 0
#define ST_MOVE_X_SLOW 1
#define ST_MOVE_PX_NORMAL 2
#define ST_MOVE_PX_FAST 3
#define ST_MOVE_PLAYER 4
#define ST_MOVE_PY 5
#define ST_MOVE_NY 6
#define ST_MOVE_IMPLODE 7
#define ST_MOVE_X_FAST 8
#define ST_MOVE_WALL 9
#define ST_MOVE_NXPY 10
#define ST_MOVE_NXNY 11

#define ST_IS_HIT_NONE 0
#define ST_IS_HIT_BBOX 1
#define ST_IS_HIT_WALL 2

#define ST_DESTROY_NONE 0
#define ST_DESTROY_DISAPPEAR 1
#define ST_DESTROY_TO_DUST 2
#define ST_DESTROY_GADGET 3
#define ST_DESTROY_PLAYER 4
#define ST_DESTROY_PLAYER_GADGETS 5
#define ST_DESTROY_BIG_TRASH 6

#define ST_FIRE_NONE 0
#define ST_FIRE_PLAYER1 1
#define ST_FIRE_PLAYER2 2
#define ST_FIRE_PLAYER3 3

#define ST_OT_WALL_SOLID 1
#define ST_OT_BIG_TRASH 2
#define ST_OT_MISSLE 3
#define ST_OT_TRASH1 4
#define ST_OT_PLAYER 5
#define ST_OT_DUST_PY 6
#define ST_OT_DUST_NY 7
#define ST_OT_TRASH_IMPLODE 8
#define ST_OT_TRASH2 9
#define ST_OT_PLAYER2 10
#define ST_OT_PLAYER3 11
#define ST_OT_GADGET 12
#define ST_OT_GADGET_IMPLODE 13
#define ST_OT_DUST_NXPY 14
#define ST_OT_DUST_NXNY 15


/*================================================================*/
/* graphics object */
/*================================================================*/

u8g2_t *st_u8g2;

u8g2_uint_t u8g_height_minus_one;


#define ST_AREA_HEIGHT (st_u8g2->height - 8)
#define ST_AREA_WIDTH (st_u8g2->width)


/*================================================================*/
/* object types */
/*================================================================*/


const st_ot st_object_types[] U8X8_PROGMEM =
{
    /* 0: empty object type */
    { 0, 0,  0, ST_DRAW_NONE, ST_MOVE_NONE, ST_DESTROY_DISAPPEAR, ST_IS_HIT_NONE, ST_FIRE_NONE },
    /* 1: wall, player will be destroyed */
    { 2, 1, 30, ST_DRAW_BBOX, ST_MOVE_WALL, ST_DESTROY_DISAPPEAR, ST_IS_HIT_WALL, ST_FIRE_NONE },
    /* ST_OT_BIG_TRASH (2) */
    { 2, 1,  0, ST_DRAW_BIG_TRASH, ST_MOVE_X_SLOW, ST_DESTROY_BIG_TRASH, ST_IS_HIT_BBOX, ST_FIRE_NONE },
    /* 3: simple space ship (player) missle */
    { 1, 0,  0, ST_DRAW_BBOX, ST_MOVE_PX_FAST, ST_DESTROY_DISAPPEAR, ST_IS_HIT_NONE, ST_FIRE_NONE },
    /* ST_OT_TRASH1 (4): trash */
    { 2, 1,  0, ST_DRAW_TRASH1, ST_MOVE_X_SLOW, ST_DESTROY_TO_DUST, ST_IS_HIT_BBOX, ST_FIRE_NONE },
    /* ST_OT_PLAYER (5): player space ship */
    { 0, 2,  0, ST_DRAW_PLAYER1, ST_MOVE_PLAYER, ST_DESTROY_PLAYER, ST_IS_HIT_BBOX, ST_FIRE_PLAYER1 },
    /* ST_OT_DUST_PY (6): Last part of trash  */
    { 0, 0,  0, ST_DRAW_BBOX, ST_MOVE_PY, ST_DESTROY_NONE, ST_IS_HIT_NONE, ST_FIRE_NONE },
    /* ST_OT_DUST_NY (7): Last part of trash  */
    { 0, 0,  0, ST_DRAW_BBOX, ST_MOVE_NY, ST_DESTROY_NONE, ST_IS_HIT_NONE, ST_FIRE_NONE },
    /* ST_OT_TRASH_IMPLODE (8): trash was hit */
    { 0, 0,  5, ST_DRAW_TRASH1, ST_MOVE_IMPLODE, ST_DESTROY_NONE, ST_IS_HIT_NONE, ST_FIRE_NONE },
    /* ST_OT_TRASH2 (9): trash */
    { 2, 1,  0, ST_DRAW_TRASH2, ST_MOVE_X_SLOW, ST_DESTROY_TO_DUST, ST_IS_HIT_BBOX, ST_FIRE_NONE },
    /* ST_OT_PLAYER2 (10): player space ship+1x enhancement */
    { 0, 2,  0, ST_DRAW_PLAYER2, ST_MOVE_PLAYER, ST_DESTROY_PLAYER_GADGETS, ST_IS_HIT_BBOX, ST_FIRE_PLAYER2 },
    /* ST_OT_PLAYER3 (11): player space ship+2x enhancement */
    { 0, 2,  0, ST_DRAW_PLAYER3, ST_MOVE_PLAYER, ST_DESTROY_PLAYER_GADGETS, ST_IS_HIT_BBOX, ST_FIRE_PLAYER3 },
    /* ST_OT_GADGET (12): adds enhancements */
    { 0, 1,  0, ST_DRAW_GADGET, ST_MOVE_X_FAST, ST_DESTROY_GADGET, ST_IS_HIT_BBOX, ST_FIRE_NONE },
    /* ST_OT_GADGET_IMPLODE (13) */
    { 0, 0, 20, ST_DRAW_GADGET, ST_MOVE_IMPLODE, ST_DESTROY_NONE, ST_IS_HIT_NONE, ST_FIRE_NONE },
    /* ST_OT_DUST_NXPY (14): Last part of trash  */
    { 0, 0,  0, ST_DRAW_BACKSLASH, ST_MOVE_NXPY, ST_DESTROY_NONE, ST_IS_HIT_NONE, ST_FIRE_NONE },
    /* ST_OT_DUST_NXNY (15): Last part of trash  */
    { 0, 0,  0, ST_DRAW_SLASH, ST_MOVE_NXNY, ST_DESTROY_NONE, ST_IS_HIT_NONE, ST_FIRE_NONE },
    
};

/*================================================================*/
/* list of all objects on the screen */
/*================================================================*/

/* use AVR RAMEND constant to derive the number of allowed objects */

#if RAMEND < 0x300 
#define ST_OBJ_CNT 25
#else
//#define ST_OBJ_CNT 45
#define ST_OBJ_CNT 60
#endif 

st_obj st_objects[ST_OBJ_CNT];

/*================================================================*/
/* about players space ship*/
/*================================================================*/

/* player position */
uint8_t st_player_pos_x;
uint8_t st_player_pos_y;

/* points */
#define ST_POINTS_PER_LEVEL 25
uint16_t st_player_points;
uint16_t st_player_points_delayed;
uint16_t st_highscore = 0;

/*================================================================*/
/* overall game state */
/*================================================================*/

#define ST_STATE_PREPARE 0
#define ST_STATE_IPREPARE 1
#define ST_STATE_GAME 2
#define ST_STATE_END 3
#define ST_STATE_IEND 4

uint8_t st_state = ST_STATE_PREPARE;

/*================================================================*/
/* game difficulty */
/*================================================================*/
uint8_t st_difficulty = 1;
#define ST_DIFF_VIS_LEN 30
#define ST_DIFF_FP 5
uint16_t st_to_diff_cnt = 0;

/*================================================================*/
/* bitmaps */
/*================================================================*/

const uint8_t st_bitmap_player1[]  = 
{ 
  /* 01100000 */ 0x060,
  /* 11111000 */ 0x0f8,
  /* 01111110 */ 0x07e,
  /* 11111000 */ 0x0f8,
  /* 01100000 */ 0x060
};

const uint8_t st_bitmap_player2[] = 
{   
  /* 01100000 */ 0x060,
  /* 01111100 */ 0x078,
  /* 01100000 */ 0x060,
  /* 11100000 */ 0x0e0,
  /* 11111000 */ 0x0f8,
  /* 01111110 */ 0x07e,
  /* 11111000 */ 0x0f8,
  /* 01100000 */ 0x060
};

const uint8_t st_bitmap_player3[] = 
{   
  /* 01100000 */ 0x060,
  /* 01111100 */ 0x078,
  /* 01100000 */ 0x060,
  /* 11100000 */ 0x0e0,
  /* 11111000 */ 0x0f8,
  /* 01111110 */ 0x07e,
  /* 11111000 */ 0x0f8,
  /* 11100000 */ 0x0e0,
  /* 01100000 */ 0x060,
  /* 01111100 */ 0x078,
  /* 01100000 */ 0x060
 };

const uint8_t st_bitmap_trash_5x5_1[] = 
{ 
  /* 01110000 */ 0x070,
  /* 11110000 */ 0x0f0,
  /* 11111000 */ 0x0f8,
  /* 01111000 */ 0x078,
  /* 00110000 */ 0x030,
};

const uint8_t st_bitmap_trash_5x5_2[] = 
{ 
  /* 00110000 */ 0x030,
  /* 11111000 */ 0x0f8,
  /* 11111000 */ 0x0f8,
  /* 11110000 */ 0x0f0,
  /* 01110000 */ 0x070,
};

const uint8_t st_bitmap_trash_7x7[] = 
{
  /* 00111000 */ 0x038,
  /* 01111100 */ 0x07c,
  /* 11111100 */ 0x0fc,
  /* 11111110 */ 0x0fe,
  /* 11111110 */ 0x0fe,
  /* 01111110 */ 0x07e,
  /* 01111000 */ 0x078,
};

const uint8_t st_bitmap_gadget[] = 
{ 
  /* 01110000 */ 0x070,
  /* 11011000 */ 0x0d8,
  /* 10001000 */ 0x088,
  /* 11011000 */ 0x0d8,
  /* 01110000 */ 0x070,
};

/*================================================================*/
/* forward definitions */
/*================================================================*/
uint8_t st_rnd(void) U8X8_NOINLINE;
static st_obj *st_GetObj(uint8_t objnr) U8X8_NOINLINE;
uint8_t st_GetMissleMask(uint8_t objnr);
uint8_t st_GetHitMask(uint8_t objnr);
int8_t st_FindObj(uint8_t ot) U8X8_NOINLINE;
void st_ClrObjs(void) U8X8_NOINLINE;
int8_t st_NewObj(void) U8X8_NOINLINE;
uint8_t st_CntObj(uint8_t ot);
uint8_t st_CalcXY(st_obj *o) U8X8_NOINLINE;
void st_SetXY(st_obj *o, uint8_t x, uint8_t y) U8X8_NOINLINE;

void st_FireStep(uint8_t is_auto_fire, uint8_t is_fire) U8X8_NOINLINE;

void st_InitTrash(uint8_t x, uint8_t y, int8_t dir);
void st_NewGadget(uint8_t x, uint8_t y);
void st_NewPlayerMissle(uint8_t x, uint8_t y) ;
void st_NewTrashDust(uint8_t x, uint8_t y, int ot);
void st_NewTrashDustAreaArgs(int16_t x, int16_t y, int ot); 
void st_SetupPlayer(uint8_t objnr, uint8_t ot);


/*================================================================*/
/* utility functions */
/*================================================================*/

char st_itoa_buf[12];
char *st_itoa(unsigned long v)
{
  volatile unsigned char i = 11;
  st_itoa_buf[11] = '\0';
  while( i > 0)
  {
      i--;
      st_itoa_buf[i] = (v % 10)+'0';
      v /= 10;
      if ( v == 0 )
	break;
  }
  return st_itoa_buf+i;
}


uint8_t st_rnd(void)
{
  return rand();
}

/*	
  for the specified index number, return the object
*/
static st_obj *st_GetObj(uint8_t objnr)
{
  return st_objects+objnr;
}


/*
  check, if this is a missle-like object (that is, can this object destroy something else)
*/ 
uint8_t st_GetMissleMask(uint8_t objnr)
{
  st_obj *o = st_GetObj(objnr);
  return u8x8_pgm_read(&(st_object_types[o->ot].missle_mask));
}

/*
  check, if this is a missle-like object (that is, can this object destroy something else)
*/ 
uint8_t st_GetHitMask(uint8_t objnr)
{
  st_obj *o = st_GetObj(objnr);
  return u8x8_pgm_read(&(st_object_types[o->ot].hit_mask));
}

/*
  search an empty object
*/
int8_t st_FindObj(uint8_t ot)
{
  int8_t i;
  for( i = 0; i < ST_OBJ_CNT; i++ )
  {
    if ( st_objects[i].ot == ot )
      return i;
  }
  return -1;
}

/*
  delete all objects
*/

void st_ClrObjs(void)
{
  int8_t i;
  for( i = 0; i < ST_OBJ_CNT; i++ )
    st_objects[i].ot = 0;
}

/*
  search an empty object
*/
int8_t st_NewObj(void)
{
  int8_t i;
  for( i = 0; i < ST_OBJ_CNT; i++ )
  {
    if ( st_objects[i].ot == 0 )
      return i;
  }
  return -1;
}

/*
  count number of objectes of the provided type
  st_CntObj(0) will return the number of empty objects, that means if
  st_CntObj(0) > 0 then st_NewObj() will return  a valid index
*/
uint8_t st_CntObj(uint8_t ot)
{
  uint8_t i;
  uint8_t cnt = 0;
  for( i = 0; i < ST_OBJ_CNT; i++ )
  {
    if ( st_objects[i].ot == ot )
      cnt++;
  }
  return cnt;
}

/*
  calculate the pixel coordinates of the reference point of an object
  return rhe x value
*/
uint8_t st_px_x, st_px_y; /* pixel within area */
uint8_t st_CalcXY(st_obj *o)
{
  //st_obj *o = st_GetObj(objnr);
  st_px_y = o->y>>ST_FP;
  st_px_x = o->x>>ST_FP;
  return st_px_x;
}

void st_SetXY(st_obj *o, uint8_t x, uint8_t y)
{
  o->x = ((int16_t)x) << ST_FP;
  o->y = ((int16_t)y) << ST_FP;
}

/*
  calculate the object bounding box and place it into some global variables
*/
int16_t st_bbox_x0, st_bbox_y0, st_bbox_x1, st_bbox_y1;  

void st_CalcBBOX(uint8_t objnr)
{
  st_obj *o = st_GetObj(objnr);
  
  st_bbox_x0 = (uint16_t)(o->x>>ST_FP);
  st_bbox_x1 = st_bbox_x0;
  st_bbox_x0 += o->x0;
  st_bbox_x1 += o->x1;

  st_bbox_y0 = (uint16_t)(o->y>>ST_FP);
  st_bbox_y1 = st_bbox_y0;
  st_bbox_y0 += o->y0;
  st_bbox_y1 += o->y1;
}

/*
  clip bbox with the view window. requires a call to st_CalcBBOX
  return 0, if the bbox is totally outside the window
*/
uint8_t st_cbbox_x0, st_cbbox_y0, st_cbbox_x1, st_cbbox_y1;
uint8_t st_ClipBBOX(void)
{
  if ( st_bbox_x0 >= ST_AREA_WIDTH )
    return 0;
  if ( st_bbox_x0 >= 0 )
    st_cbbox_x0  = (uint16_t)st_bbox_x0;
  else
    st_cbbox_x0 = 0;

  if ( st_bbox_x1 < 0 )
    return 0;
  if ( st_bbox_x1 < ST_AREA_WIDTH )
    st_cbbox_x1  = (uint16_t)st_bbox_x1;
  else
    st_cbbox_x1 = ST_AREA_WIDTH-1;

  if ( st_bbox_y0 >= ST_AREA_HEIGHT )
    return 0;
  if ( st_bbox_y0 >= 0 )
    st_cbbox_y0  = (uint16_t)st_bbox_y0;
  else
    st_cbbox_y0 = 0;

  if ( st_bbox_y1 < 0 )
    return 0;
  if ( st_bbox_y1 < ST_AREA_HEIGHT )
    st_cbbox_y1  = (uint16_t)st_bbox_y1;
  else
    st_cbbox_y1 = ST_AREA_HEIGHT-1;
  
  return 1;
}


/*================================================================*/
/* universal member functions */
/*================================================================*/


uint8_t st_IsOut(uint8_t objnr)
{
  st_CalcBBOX(objnr);
  if ( st_bbox_x0 >= ST_AREA_WIDTH )
    return 1;
  if ( st_bbox_x1 < 0 )
    return 1;
  if ( st_bbox_y0 >= ST_AREA_HEIGHT )
    return 1;
  if ( st_bbox_y1 < 0 )
    return 1;
  return 0;
}

void st_Disappear(uint8_t objnr)
{
  st_obj *o = st_GetObj(objnr);
  st_player_points += u8x8_pgm_read(&(st_object_types[o->ot].points));
  o->ot = 0;
}

/*================================================================*/
/* type dependent member functions */
/*================================================================*/

void st_Move(uint8_t objnr)
{
  st_obj *o = st_GetObj(objnr);
  switch(u8x8_pgm_read(&(st_object_types[o->ot].move_fn)))
  {
    case ST_MOVE_NONE:
      break;
    case ST_MOVE_X_SLOW:
      o->x -= (1<<ST_FP)/8;
      o->x -= st_difficulty;
      o->y += (int16_t)o->tmp;
      if ( o->y >= ((ST_AREA_HEIGHT-1) << ST_FP) || o->y <= 0 )
	o->tmp = - o->tmp;
      break;
    case ST_MOVE_X_FAST:
      o->x -= (1<<ST_FP)/2;
      o->y += (int16_t)o->tmp;
      if ( o->y >= ((ST_AREA_HEIGHT-1) << ST_FP) || o->y <= 0 )
	o->tmp = - o->tmp;
      break;
    case ST_MOVE_PX_NORMAL:
      o->x += (1<<ST_FP)/4;
      break;
    case ST_MOVE_PX_FAST:
      o->x += (1<<ST_FP);
      break;
    case ST_MOVE_PLAYER:
      o->x = st_player_pos_x<<ST_FP;
      o->y = st_player_pos_y<<ST_FP;
      break;
    case ST_MOVE_PY:
      o->y += 3*ST_FP;
      break;
    case ST_MOVE_NY:
      o->y -= 3*ST_FP;
      break;
    case ST_MOVE_NXPY:
      o->y += 3*ST_FP;
      o->x -= 3*ST_FP;
      break;
    case ST_MOVE_NXNY:
      o->y -= 3*ST_FP;
      o->x -= 3*ST_FP;
      break;
    case ST_MOVE_IMPLODE:
      o->tmp++;
      if ( (o->tmp & 0x03) == 0 )
      {
	if ( o->x0 != o->x1 )
	  o->x0++;
	else
	    st_Disappear(objnr);
      }
      break;
    case ST_MOVE_WALL:
      o->x -= 1;
      o->x -= (st_difficulty>>1);
      break;
  }
}

void st_DrawBBOX(uint8_t objnr)
{
  uint8_t y0, y1;
  /*st_obj *o = st_GetObj(objnr);*/
  st_CalcBBOX(objnr);
  if ( st_ClipBBOX() == 0 )
    return;
  /* st_cbbox_x0, st_cbbox_y0, st_cbbox_x1, st_cbbox_y1; */

  
  // w = st_cbbox_x1-st_cbbox_x0;
  // w++;
  // h = st_cbbox_y1-st_cbbox_y0;
  // h++;
  
  u8g2_SetDrawColor(st_u8g2, 1);
  y0 = u8g_height_minus_one - st_cbbox_y0;
  y1 = u8g_height_minus_one - st_cbbox_y1;
  
  u8g2_DrawFrame(st_u8g2, st_cbbox_x0, y1, st_cbbox_x1-st_cbbox_x0+1, y0-y1+1);

}

void st_DrawBitmap(uint8_t objnr, const uint8_t * bm, uint8_t w, uint8_t h)
{
  /* st_obj *o = st_GetObj(objnr); */
  st_CalcBBOX(objnr);
  /* result is here: int16_t st_bbox_x0, st_bbox_y0, st_bbox_x1, st_bbox_y1 */
  
  u8g2_DrawBitmap(st_u8g2, st_bbox_x0, u8g_height_minus_one - st_bbox_y1, (w+7)/8, h, bm);
  
 }

void st_DrawObj(uint8_t objnr)
{
  st_obj *o = st_GetObj(objnr);
  switch(u8x8_pgm_read(&(st_object_types[o->ot].draw_fn)))
  {
    case ST_DRAW_NONE:
      break;
    case ST_DRAW_BBOX:
      st_DrawBBOX(objnr);
      break;
    case ST_DRAW_TRASH1:
      st_DrawBitmap(objnr, st_bitmap_trash_5x5_1,o->x1-o->x0+1, 5);
      break;
    case ST_DRAW_TRASH2:
      st_DrawBitmap(objnr, st_bitmap_trash_5x5_2,o->x1-o->x0+1, 5);
      break;
    case ST_DRAW_BIG_TRASH:
      st_DrawBitmap(objnr, st_bitmap_trash_7x7,o->x1-o->x0+1, 7);
      break;
    case ST_DRAW_PLAYER1:
      st_DrawBitmap(objnr, st_bitmap_player1,7,5);
      break;
    case ST_DRAW_PLAYER2:
      st_DrawBitmap(objnr, st_bitmap_player2,7,8);
      break;
    case ST_DRAW_PLAYER3:
      st_DrawBitmap(objnr, st_bitmap_player3,7,11);
      break;
    case ST_DRAW_GADGET:
      /* could use this proc, but... */
      /* st_DrawBitmap(objnr, st_bitmap_gadget,o->x1-o->x0+1, 5); */
      /* ... this one looks also funny. */
      st_DrawBitmap(objnr, st_bitmap_gadget,5,5);
      break;
    case ST_DRAW_BACKSLASH:
      {
        uint8_t x;
        uint8_t y;
        x = st_CalcXY(o);
        y = st_px_y;
        
        u8g2_SetDrawColor(st_u8g2, 1);  
        u8g2_DrawPixel(st_u8g2, x, u8g_height_minus_one - y);  
        x++; y--;
        u8g2_DrawPixel(st_u8g2, x, u8g_height_minus_one - y);  
        x++; y--;
        u8g2_DrawPixel(st_u8g2, x, u8g_height_minus_one - y);  	
      }      
     break;
    case ST_DRAW_SLASH:
      {
        uint8_t x;
        uint8_t y;
        x = st_CalcXY(o);
        y = st_px_y;
          
        u8g2_SetDrawColor(st_u8g2, 1);  
        u8g2_DrawPixel(st_u8g2, x, u8g_height_minus_one - y);  
        x++; y++;
        u8g2_DrawPixel(st_u8g2, x, u8g_height_minus_one - y);  
        x++; y++;
        u8g2_DrawPixel(st_u8g2, x, u8g_height_minus_one - y);  	
     }      
     break;
  }
}

uint8_t st_IsHitBBOX(uint8_t objnr, uint8_t x, uint8_t y)
{
  st_CalcBBOX(objnr);
  if ( st_ClipBBOX() == 0 ) 
    return 0;	/* obj is outside (not visible) */
  if ( x < st_cbbox_x0 )
    return 0;
  if ( x > st_cbbox_x1 )
    return 0;
  if ( y < st_cbbox_y0 )
    return 0;
  if ( y > st_cbbox_y1 )
    return 0;
  return 1;
}
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
void loop(void) {
  uint8_t x = 6;
  uint8_t y = 128;

  u8g2.setFont(u8g2_font_6x10_tr);
  u8g2.setFontDirection(0);
  u8g2.setFontRefHeightAll();

  st_Setup(u8g2.getU8g2());
  for(;;)
  {
    st_Step(x, y, !digitalRead(pin_start),/* is_auto_fire */ 0, /* is_fire */ digitalRead(pin_fire));
    u8g2.firstPage();
    do
    {
      st_Draw(0);
    } while( u8g2.nextPage() );
    
    
    if ( !digitalRead(pin_up) && y < 192 ) { // 
      y++;
    }
    
    if ( !digitalRead(pin_down) && y>=64 ) { // 
      y--;
    }
    
    if ( !digitalRead(pin_right) && x < 120 ) { // 
      x++;
    }
    
    if ( !digitalRead(pin_left) && x>6 ) { // 
      x--;
    }

    if(st_state == ST_STATE_END)
    {
      x = 6;
      y = 128;
    }
  }
}

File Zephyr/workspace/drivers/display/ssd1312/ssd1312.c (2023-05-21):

/*
 * Copyright (c) 2018 PHYTEC Messtechnik GmbH
 *
 * SPDX-License-Identifier: Apache-2.0
 */

#define DT_DRV_COMPAT solomon_ssd1312fb

#include <zephyr/logging/log.h>
LOG_MODULE_REGISTER(ssd1312, CONFIG_DISPLAY_LOG_LEVEL);

#include <string.h>
#include <zephyr/device.h>
#include <zephyr/init.h>
#include <zephyr/drivers/gpio.h>
#include <zephyr/drivers/i2c.h>
#include <zephyr/kernel.h>

#include "ssd1312_regs.h"
#include <zephyr/display/cfb.h>

#if DT_INST_PROP(0, segment_remap) == 1
#define SSD1312_PANEL_SEGMENT_REMAP	true
#else
#define SSD1312_PANEL_SEGMENT_REMAP	false
#endif

#if DT_INST_PROP(0, com_invdir) == 1
#define SSD1312_PANEL_COM_INVDIR	true
#else
#define SSD1312_PANEL_COM_INVDIR	false
#endif

#if DT_INST_PROP(0, com_sequential) == 1
#define SSD1312_COM_PINS_HW_CONFIG	SSD1312_SET_PADS_HW_SEQUENTIAL
#else
#define SSD1312_COM_PINS_HW_CONFIG	SSD1312_SET_PADS_HW_ALTERNATIVE
#endif

#define SSD1312_PANEL_NUMOF_PAGES	(DT_INST_PROP(0, height) / 8)
#define SSD1312_CLOCK_DIV_RATIO		0x0
#define SSD1312_CLOCK_FREQUENCY		0x8
#define SSD1312_PANEL_VCOM_DESEL_LEVEL	0x40
#define SSD1312_PANEL_PUMP_VOLTAGE	SSD1312_SET_PUMP_VOLTAGE_90

#ifndef SSD1312_ADDRESSING_MODE
#define SSD1312_ADDRESSING_MODE		(SSD1312_SET_MEM_ADDRESSING_HORIZONTAL)
#endif

struct ssd1312_config {
#if DT_INST_ON_BUS(0, i2c)
	struct i2c_dt_spec bus;
#elif DT_INST_ON_BUS(0, spi)
	struct spi_dt_spec bus;
	struct gpio_dt_spec data_cmd;
#endif
	struct gpio_dt_spec reset;
};

struct ssd1312_data {
	uint8_t contrast;
	uint8_t scan_mode;
};

#if DT_INST_ON_BUS(0, i2c)

static inline bool ssd1312_bus_ready(const struct device *dev)
{
	const struct ssd1312_config *config = dev->config;

	return device_is_ready(config->bus.bus);
}

static inline int ssd1312_write_bus(const struct device *dev,
				    uint8_t *buf, size_t len, bool command)
{
	const struct ssd1312_config *config = dev->config;

	return i2c_burst_write_dt(&config->bus,
				  command ? SSD1312_CONTROL_ALL_BYTES_CMD :
				  SSD1312_CONTROL_ALL_BYTES_DATA,
				  buf, len);
}

#endif

static inline int ssd1312_set_panel_orientation(const struct device *dev)
{
	uint8_t cmd_buf[] = {
		(SSD1312_PANEL_SEGMENT_REMAP ?
		 SSD1312_SET_SEGMENT_MAP_REMAPED :
		 SSD1312_SET_SEGMENT_MAP_NORMAL),
		(SSD1312_PANEL_COM_INVDIR ?
		 SSD1312_SET_COM_OUTPUT_SCAN_FLIPPED :
		 SSD1312_SET_COM_OUTPUT_SCAN_NORMAL)
	};

	return ssd1312_write_bus(dev, cmd_buf, sizeof(cmd_buf), true);
}

static inline int ssd1312_set_timing_setting(const struct device *dev)
{
	uint8_t cmd_buf[] = {
		SSD1312_SET_CLOCK_DIV_RATIO,
		(SSD1312_CLOCK_FREQUENCY << 4) | SSD1312_CLOCK_DIV_RATIO,
		SSD1312_SET_CHARGE_PERIOD,
		DT_INST_PROP(0, prechargep),
		SSD1312_SET_VCOM_DESELECT_LEVEL,
		SSD1312_PANEL_VCOM_DESEL_LEVEL
	};

	return ssd1312_write_bus(dev, cmd_buf, sizeof(cmd_buf), true);
}

static inline int ssd1312_set_hardware_config(const struct device *dev)
{
	uint8_t cmd_buf[] = {
		SSD1312_SET_START_LINE,
		SSD1312_SET_DISPLAY_OFFSET,
		DT_INST_PROP(0, display_offset),
		SSD1312_SET_PADS_HW_CONFIG,
		SSD1312_COM_PINS_HW_CONFIG,
		SSD1312_SET_MULTIPLEX_RATIO,
		DT_INST_PROP(0, multiplex_ratio)
	};

	return ssd1312_write_bus(dev, cmd_buf, sizeof(cmd_buf), true);
}

static inline int ssd1312_set_charge_pump(const struct device *dev)
{
	uint8_t cmd_buf[] = {
		SSD1312_SET_CHARGE_PUMP_ON,
		SSD1312_SET_CHARGE_PUMP_ON_ENABLED,
		SSD1312_PANEL_PUMP_VOLTAGE,
	};

	return ssd1312_write_bus(dev, cmd_buf, sizeof(cmd_buf), true);
}

static int ssd1312_resume(const struct device *dev)
{
	uint8_t cmd_buf[] = {
		SSD1312_DISPLAY_ON,
	};

	return ssd1312_write_bus(dev, cmd_buf, sizeof(cmd_buf), true);
}

static int ssd1312_suspend(const struct device *dev)
{
	uint8_t cmd_buf[] = {
		SSD1312_DISPLAY_OFF,
	};

	return ssd1312_write_bus(dev, cmd_buf, sizeof(cmd_buf), true);
}

static int ssd1312_write(const struct device *dev, const uint16_t x, const uint16_t y,
			 const struct display_buffer_descriptor *desc,
			 const void *buf)
{
	size_t buf_len;

	if (desc->pitch < desc->width) {
		LOG_ERR("Pitch is smaller then width");
		return -1;
	}

	buf_len = MIN(desc->buf_size, desc->height * desc->width / 8);
	if (buf == NULL || buf_len == 0U) {
		LOG_ERR("Display buffer is not available");
		return -1;
	}

	if (desc->pitch > desc->width) {
		LOG_ERR("Unsupported mode");
		return -1;
	}

	if ((y & 0x7) != 0U) {
		LOG_ERR("Unsupported origin");
		return -1;
	}

	LOG_DBG("x %u, y %u, pitch %u, width %u, height %u, buf_len %u",
		x, y, desc->pitch, desc->width, desc->height, buf_len);

#if defined(CONFIG_SSD1312_DEFAULT)
	uint8_t cmd_buf[] = {
		SSD1312_SET_MEM_ADDRESSING_MODE,
		SSD1312_ADDRESSING_MODE,
		SSD1312_SET_COLUMN_ADDRESS,
		x,
		(x + desc->width - 1),
		SSD1312_SET_PAGE_ADDRESS,
		y/8,
		((y + desc->height)/8 - 1)
	};

	if (ssd1312_write_bus(dev, cmd_buf, sizeof(cmd_buf), true)) {
		LOG_ERR("Failed to write command");
		return -1;
	}

	return ssd1312_write_bus(dev, (uint8_t *)buf, buf_len, false);
#endif

	return 0;
}

static int ssd1312_read(const struct device *dev, const uint16_t x,
			const uint16_t y,
			const struct display_buffer_descriptor *desc,
			void *buf)
{
	LOG_ERR("Unsupported");
	return -ENOTSUP;
}

static void *ssd1312_get_framebuffer(const struct device *dev)
{
	LOG_ERR("Unsupported");
	return NULL;
}

static int ssd1312_set_brightness(const struct device *dev,
				  const uint8_t brightness)
{
	LOG_WRN("Unsupported");
	return -ENOTSUP;
}

static int ssd1312_set_contrast(const struct device *dev, const uint8_t contrast)
{
	uint8_t cmd_buf[] = {
		SSD1312_SET_CONTRAST_CTRL,
		contrast,
	};

	return ssd1312_write_bus(dev, cmd_buf, sizeof(cmd_buf), true);
}

static void ssd1312_get_capabilities(const struct device *dev,
				     struct display_capabilities *caps)
{
	memset(caps, 0, sizeof(struct display_capabilities));
	caps->x_resolution = DT_INST_PROP(0, width);
	caps->y_resolution = DT_INST_PROP(0, height);
	caps->supported_pixel_formats = PIXEL_FORMAT_MONO10;
	caps->current_pixel_format = PIXEL_FORMAT_MONO10;
	caps->screen_info = SCREEN_INFO_MONO_VTILED;
}

static int ssd1312_set_orientation(const struct device *dev,
				   const enum display_orientation
				   orientation)
{
	LOG_ERR("Unsupported");
	return -ENOTSUP;
}

static int ssd1312_set_pixel_format(const struct device *dev,
				    const enum display_pixel_format pf)
{
	if (pf == PIXEL_FORMAT_MONO10) {
		return 0;
	}
	LOG_ERR("Unsupported");
	return -ENOTSUP;
}
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

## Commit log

2023-01-27 Created Board Rev 1.A
    added kicad project
    replaced gd32vf103c with rp2040
    switched to esp32-c3
    added library for touch controler, changed filename of host to host, added dcdc circuit, switched touch controler IC
    added antenna and and flash
    fixed relative pathing
    added display circuit
    replaced capacitive with resitive touch pads
    added round resisitve touch pads
    updated circuits
    renamed buttons
    added furhter resitive touch pads
    added display and usb c footprints
    minor adaptions and fixes to library symbols and footprints
    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
    [capacitive_touch_circuit.kicad_sch, display_circuit.kicad_sch, host.kicad_sch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]
2023-01-27 initial configuration for Zephyr board setup - needs work
2023-02-03 fixes in device tree
2023-02-05 minor tweaks in design, added thermal relief vias
    [power_circuit.kicad_sch, system-on-a-business-card.kicad_pcb]
2023-02-05 added interactive BOM
2023-02-05 updated documentation, fixed bom export
    [display_circuit.kicad_sch, system-on-a-business-card.kicad_pcb]
2023-03-22 fixed #12 connected OLED VDD pins to 3.3V power line
    [display_circuit.kicad_sch, host.kicad_sch, power_circuit.kicad_sch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]
2023-03-22 fixes #11: Footprint of Flash IC corrected
    [display_circuit.kicad_sch, host.kicad_sch, power_circuit.kicad_sch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]
2023-03-31 fixes #15: moved wire to connecting D1 from L3 to C24
    [system-on-a-business-card.kicad_pcb]
2023-03-31 resolves #13: changed resistor for LED from 121R to 47k to reduce brightness significantly
    [power_circuit.kicad_sch, system-on-a-business-card.kicad_pcb]
2023-03-31 Updated documentation and production files
    [system-on-a-business-card.kicad_pcb]
2023-04-06 fixed EEPROM save high score bug
    [SpaceTrash.ino]
2023-04-06 fixed zephyr board definition
    [main.c]
2023-04-10 fixes #17: updates resistor values R53 and R54, updated board revision silkscreen
    [power_circuit.kicad_sch, system-on-a-business-card.kicad_pcb]
2023-04-15 #4: initial setup for OLED driver
2023-04-23 #4: fixed project setup to build with drivers
    [main.c, ssd1312.c]
2023-04-23 #4: clean up of example application repository and initial kconfig for board
2023-05-20 #4 clean up of drivers
2023-06-10 renamed board_test to workspace
2023-06-10 renamed app to board_test
